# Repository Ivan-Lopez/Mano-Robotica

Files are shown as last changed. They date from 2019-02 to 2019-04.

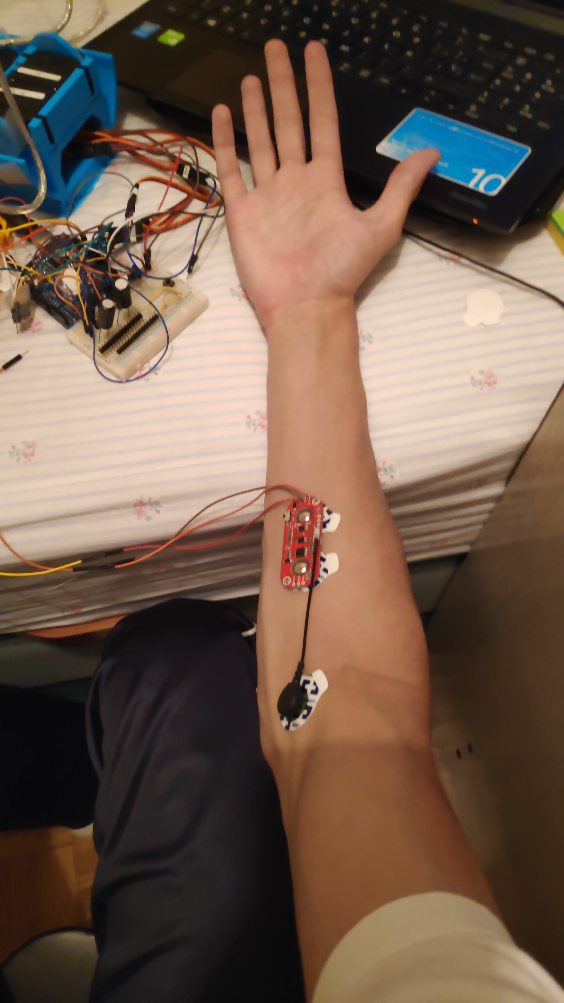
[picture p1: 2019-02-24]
Images/others/MuscleSensor-Colocación en el brazo.jpg

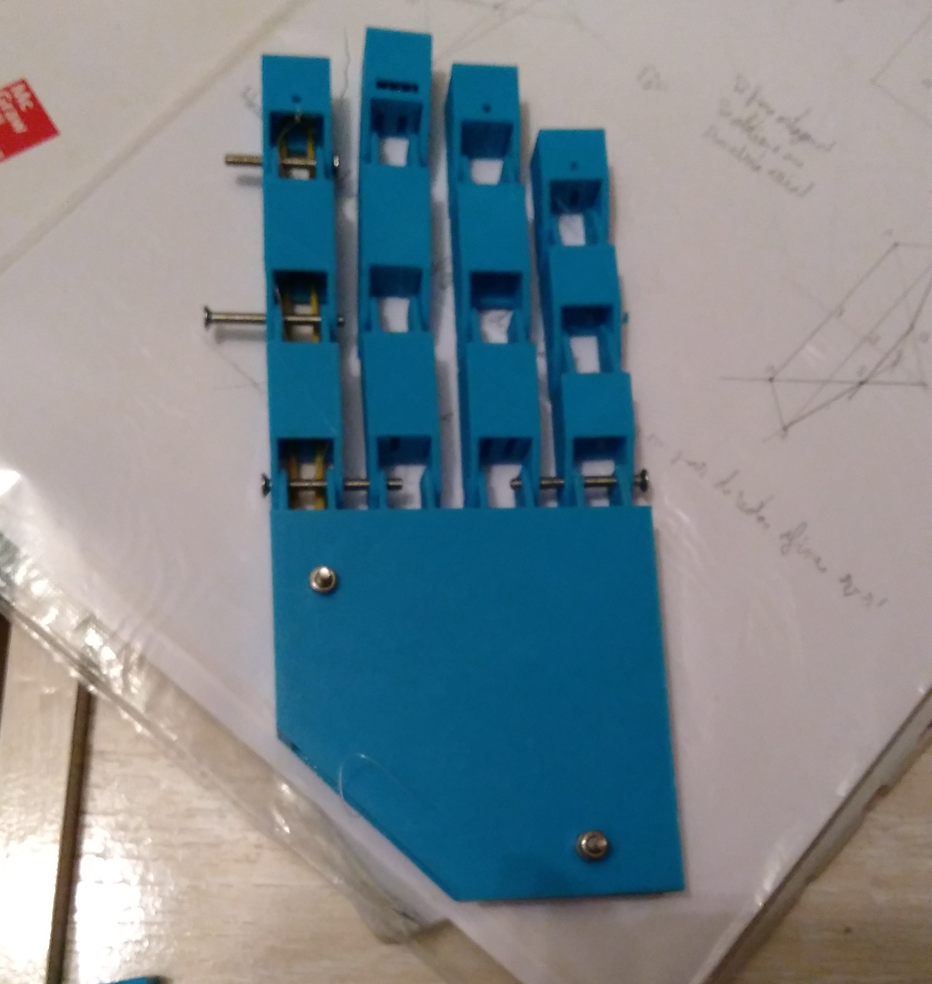
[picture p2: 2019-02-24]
Images/others/palma1(1).png

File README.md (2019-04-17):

# Mano Robotica [ES]

Este es el proyecto de investigación de Bachillerato que se presentó para el curso 2018-2019 en el IES Palas Atenea.
El diseño se comenzó en la versión 0.15 de FreeCAD y después se continuó en la 0.16.

Dentro de la carpeta FreeCAD-master file, se encuentra el diseño global, el archivo "mano+pulgar.FCStd", con todos los intentos fallidos y pruebas escondidos (y una mala organización debido a que fue mi primer proyecto tan grande).

En la carpeta Diseños se encuentran todas las piezas en formato .stl para su directa impresión.

En la carpeta Arduino files, los programas Arduino para controlar la mano mediante los sensores flexibles o musculares.

Algunos vídeos del funcionamiento:
  - Sensores flexibles(Guante): https://drive.google.com/file/d/11Kb9g7OQmceqUr2YcnktoNpW7YNgNKIl/view?usp=sharing 
  - Sensores musculares: https://drive.google.com/file/d/1Bvhk9YkBuKc7p54vJVHqvYE_SyeNIpOb/view?usp=sharing

# Robotic Hand [EN]

This is the project presented in the 2018-2019 schoolyear at Palas Atenea High School.
The design was started in the 0.15 version of FreeCAD and then continued in the 0.16 version.

In the "FreeCAD-master file" directory, you can find the global design ("mano+pulgar.FCStd"), which includes all the fail attempts and tests hidden (and a poor organization due to it was my first project of its size).

In the "Designs" directory, you can fin all the parts in .stl format.

In the "Arduino Files", the Arduino programs to control the hand through the flex sensor or muscle sensors.

Some videos:
  - Flex sensors (glove): https://drive.google.com/file/d/11Kb9g7OQmceqUr2YcnktoNpW7YNgNKIl/view?usp=sharing 
  - Muscle sensors: https://drive.google.com/file/d/1Bvhk9YkBuKc7p54vJVHqvYE_SyeNIpOb/view?usp=sharing

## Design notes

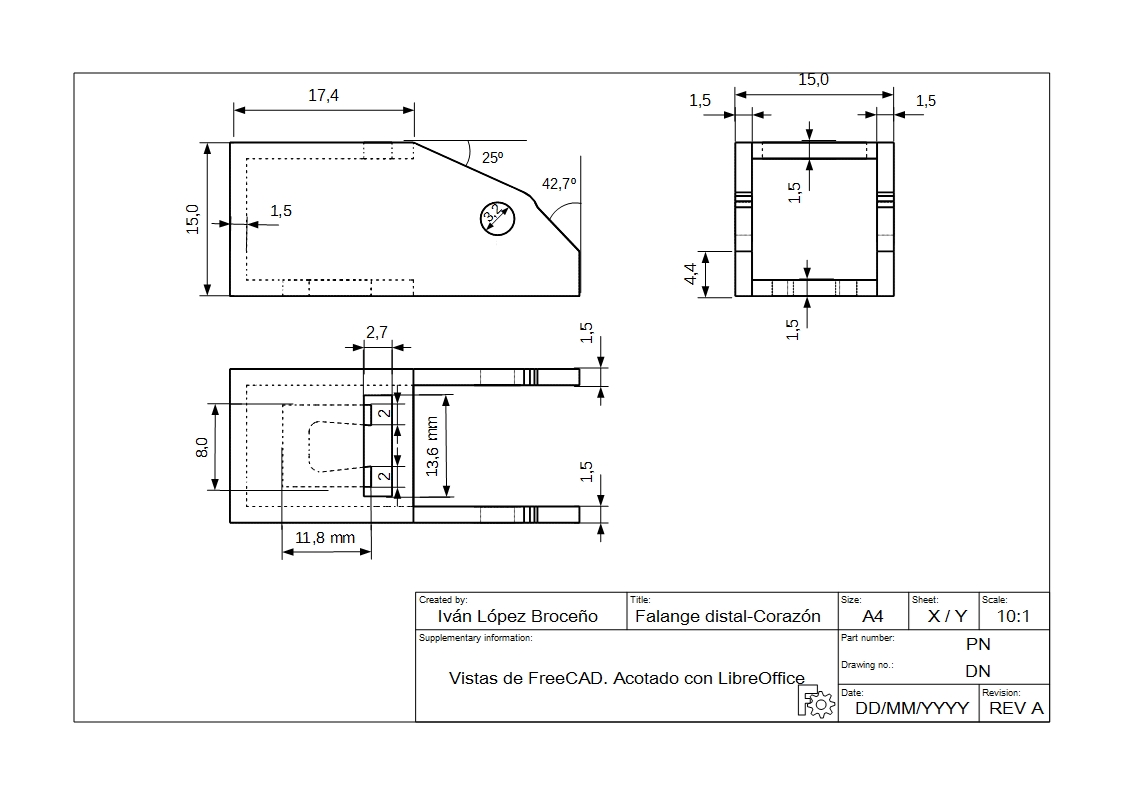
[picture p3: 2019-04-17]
Images/plans/falange distal-corazon.jpg

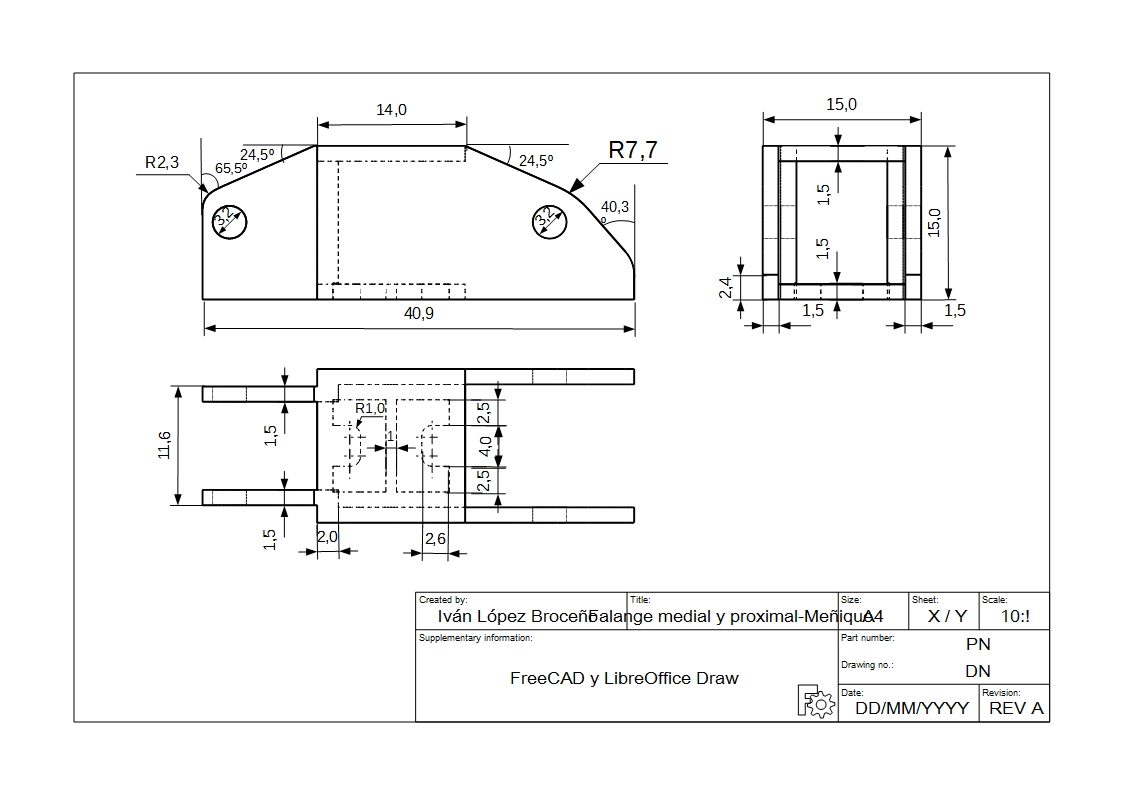
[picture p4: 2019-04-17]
Images/plans/falange medial y proximal-meñique.jpg

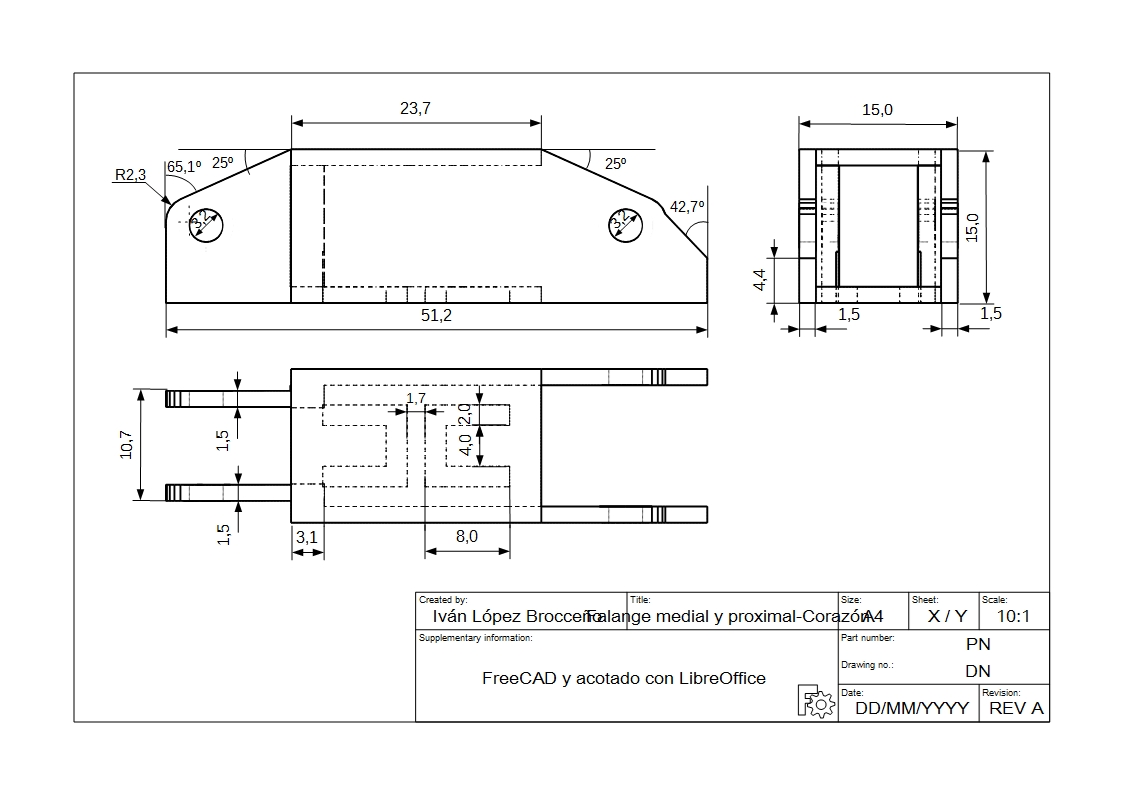
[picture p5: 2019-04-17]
Images/plans/Falange medial y proximal-Corazón.jpg

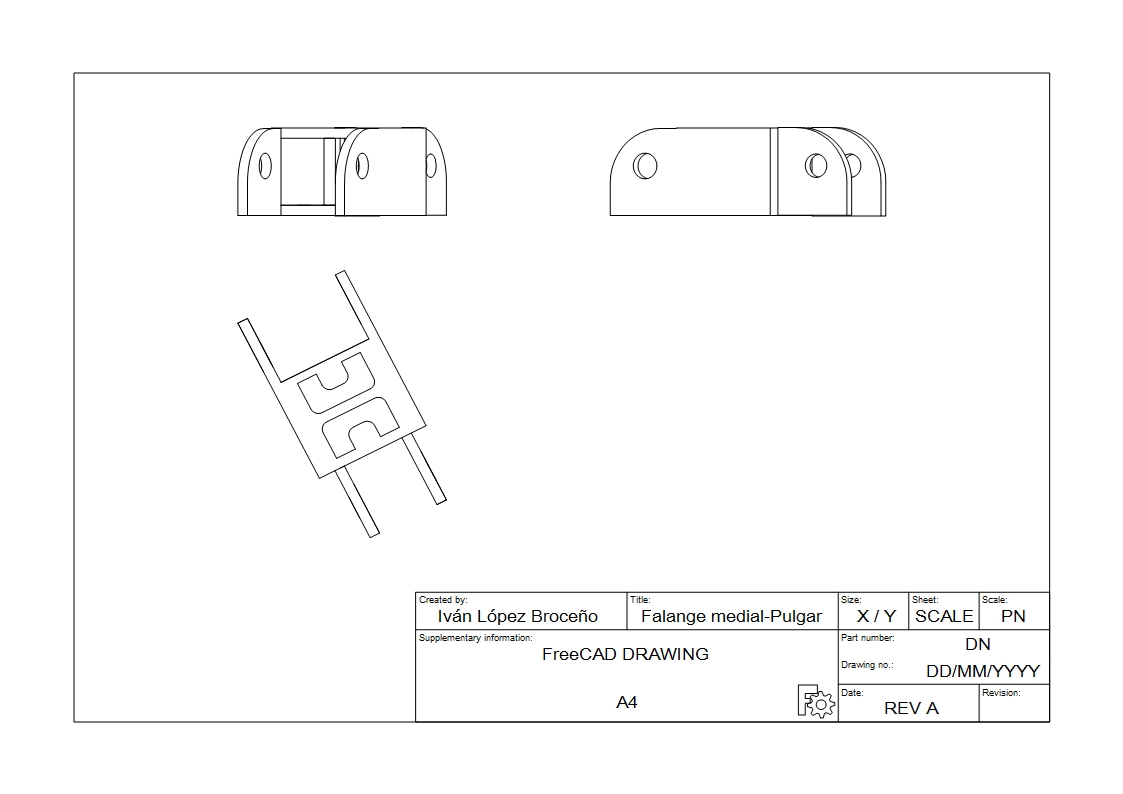
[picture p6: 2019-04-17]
Images/plans/falange medial-pulgar.jpg

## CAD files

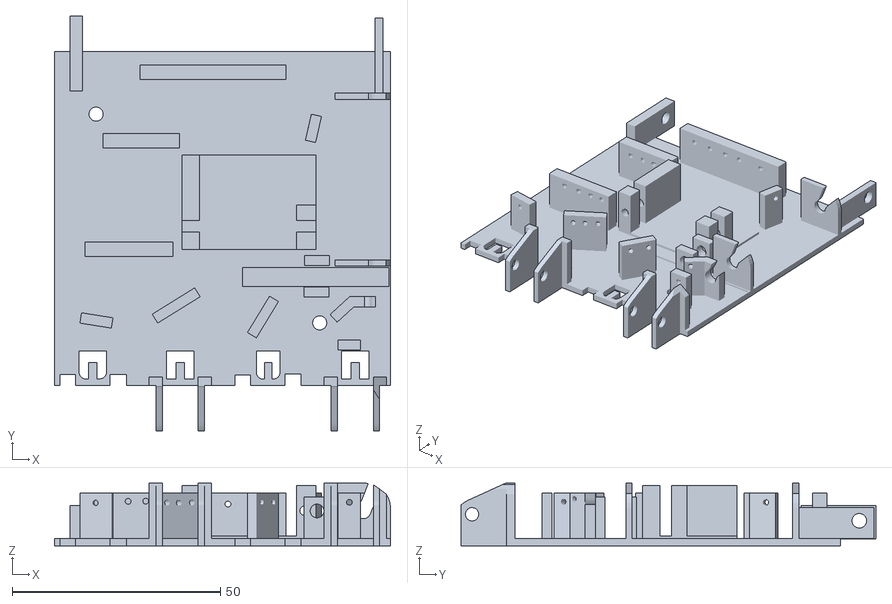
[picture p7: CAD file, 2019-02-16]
Diseños-Designs/Palma-Palm/PalmaInferior.stl
80.7 x 99.6 x 15.0

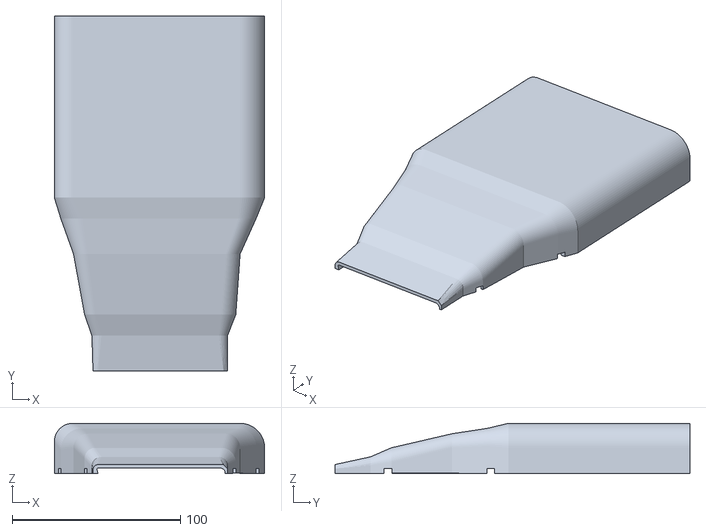
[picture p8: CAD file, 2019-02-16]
Diseños-Designs/Antebrazo-Forearm/TapaAntebrazo-ForearmCover.stl
125.0 x 211.0 x 29.9

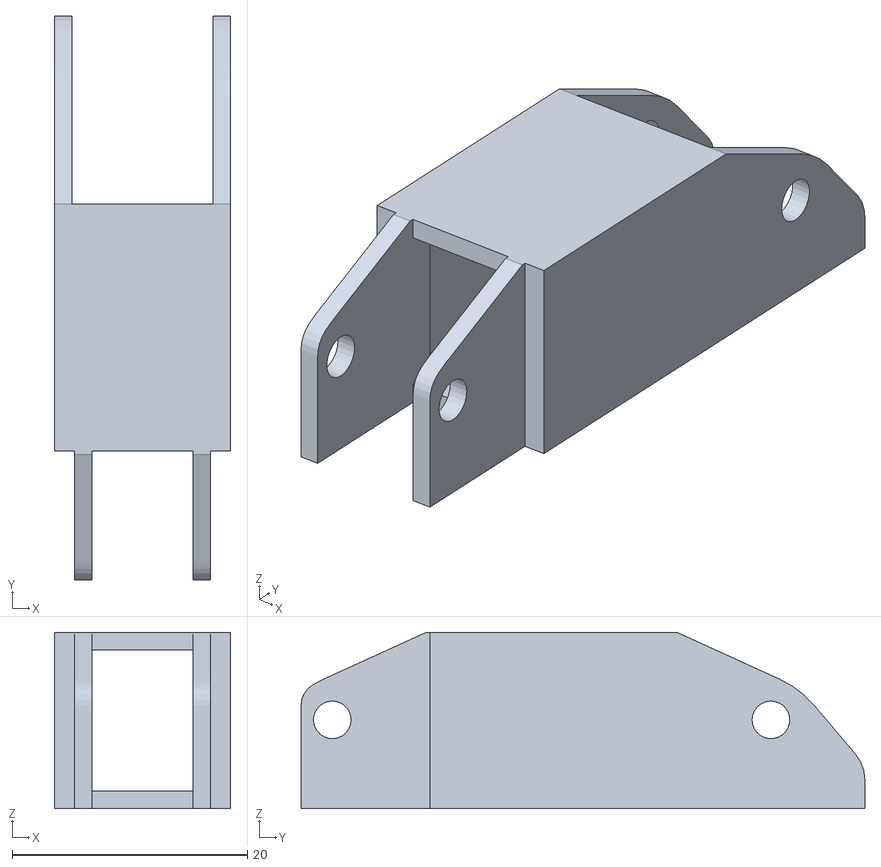
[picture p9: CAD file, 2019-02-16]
Diseños-Designs/Dedos-Fingers/Anular-Ring Finger/falange2-anular.stl
15.0 x 48.0 x 15.0

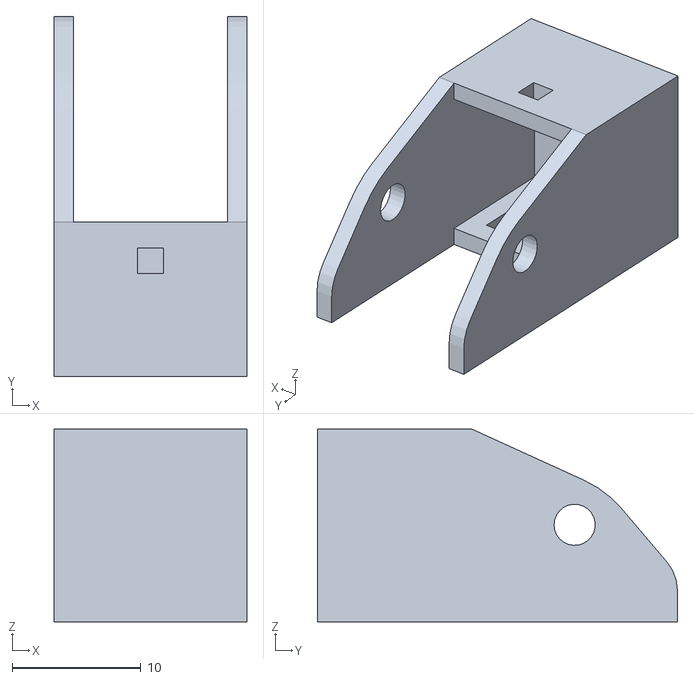
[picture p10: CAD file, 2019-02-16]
Diseños-Designs/Dedos-Fingers/Meñique-Little Finger/falange1-meñique.stl
15.0 x 28.0 x 15.0

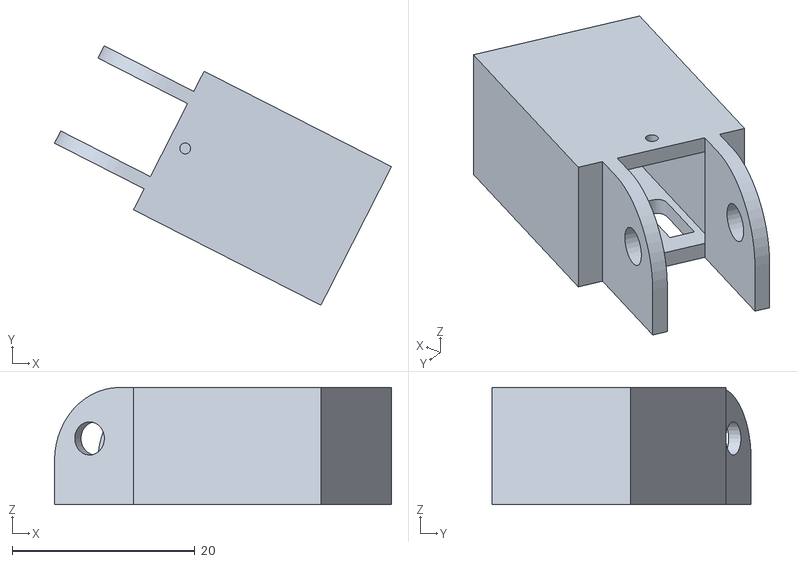
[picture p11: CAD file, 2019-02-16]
Diseños-Designs/Dedos-Fingers/Pulgar-Thumb/falange1-pulgar.stl
36.8 x 28.4 x 12.8

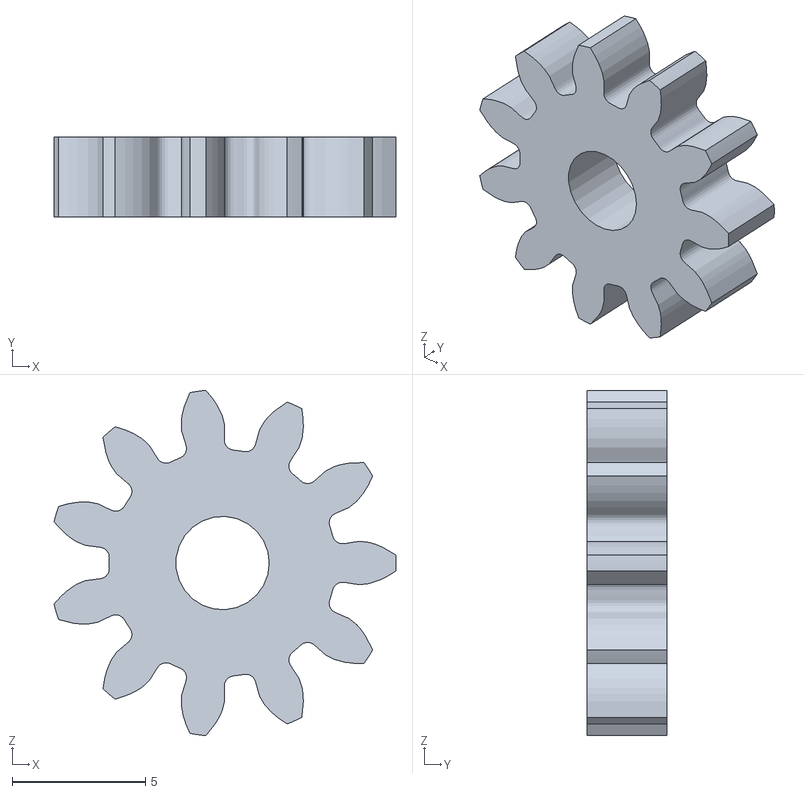
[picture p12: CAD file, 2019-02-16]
Diseños-Designs/Palma-Palm/Engranajes/engranaje-pulgar(piñon)).stl
12.8 x 3.00 x 12.9

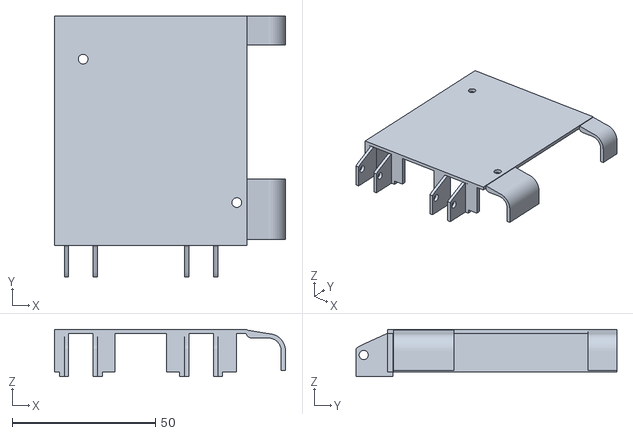
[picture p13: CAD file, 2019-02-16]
Diseños-Designs/Palma-Palm/PalmaSuperior.stl
80.7 x 91.1 x 16.5

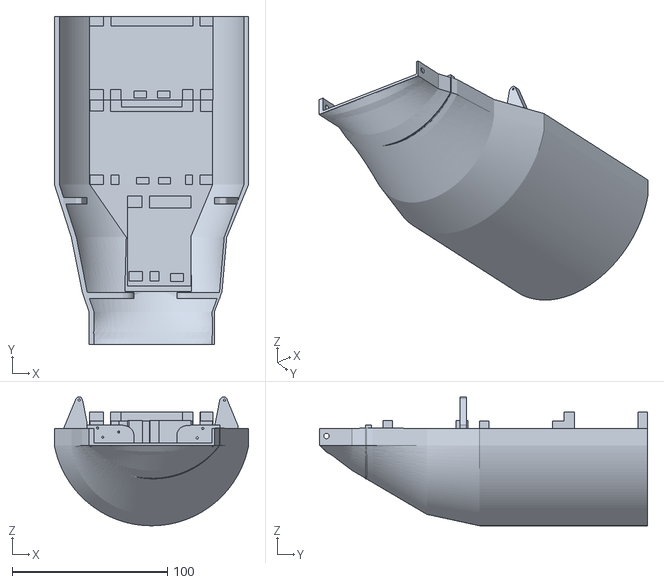
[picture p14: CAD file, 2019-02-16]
Diseños-Designs/Antebrazo-Forearm/Antebrazo(inferior)-Forearm.stl
125.0 x 211.0 x 82.7

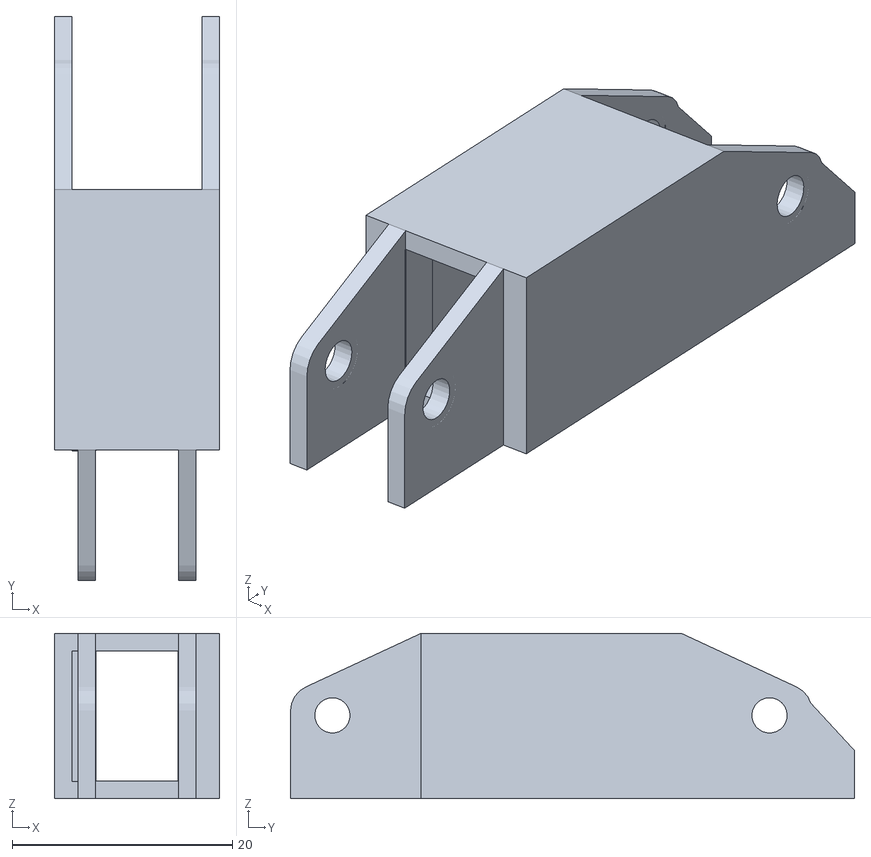
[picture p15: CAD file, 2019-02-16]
Diseños-Designs/Dedos-Fingers/Corazón-Middle Finger/falange2-corazon.stl
15.0 x 51.2 x 15.0

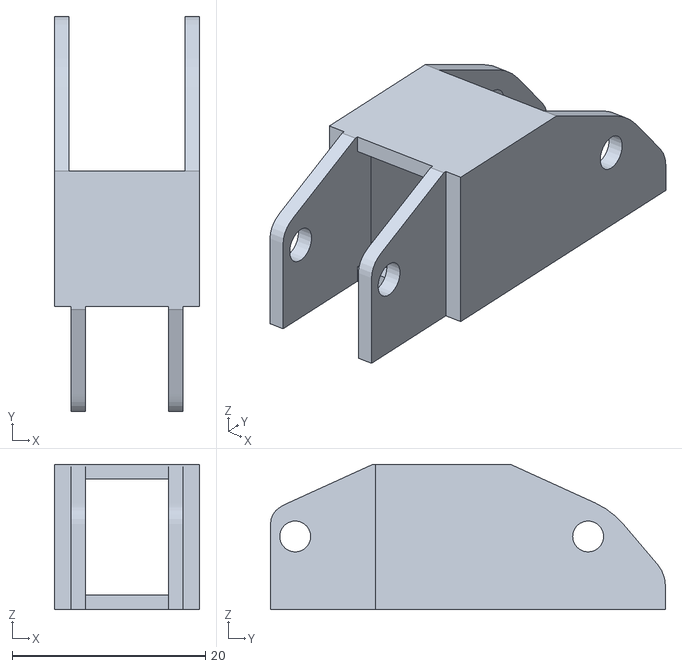
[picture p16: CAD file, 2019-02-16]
Diseños-Designs/Dedos-Fingers/Meñique-Little Finger/falange3-meñique.stl
15.0 x 40.9 x 15.0

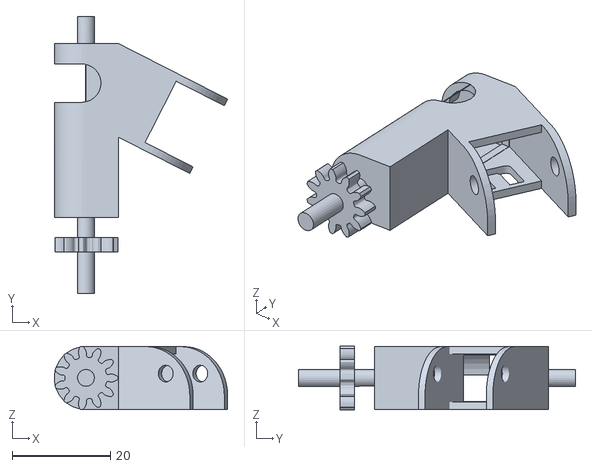
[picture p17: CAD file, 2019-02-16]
Diseños-Designs/Dedos-Fingers/Pulgar-Thumb/eje-falange3-pulgar.stl
35.3 x 56.4 x 12.9

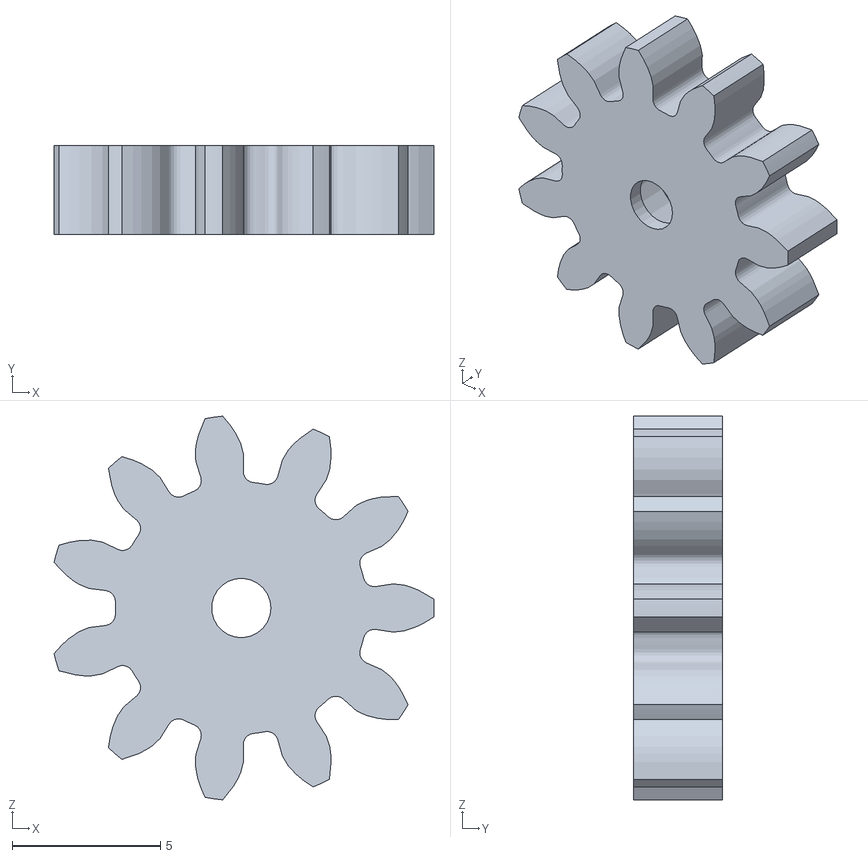
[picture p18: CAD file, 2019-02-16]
Diseños-Designs/Palma-Palm/Engranajes/engranaje-pulgar(motor).stl
12.8 x 3.00 x 12.9

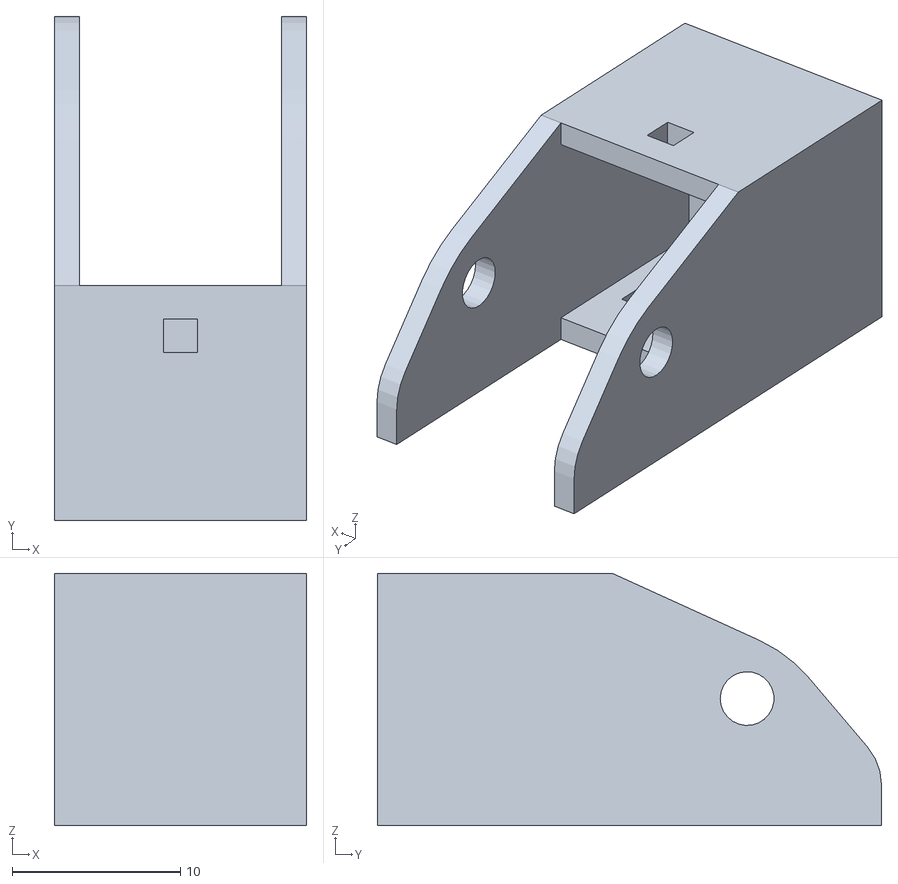
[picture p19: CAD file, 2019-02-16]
Diseños-Designs/Dedos-Fingers/Anular-Ring Finger/falange1-anular.stl
15.0 x 30.0 x 15.0

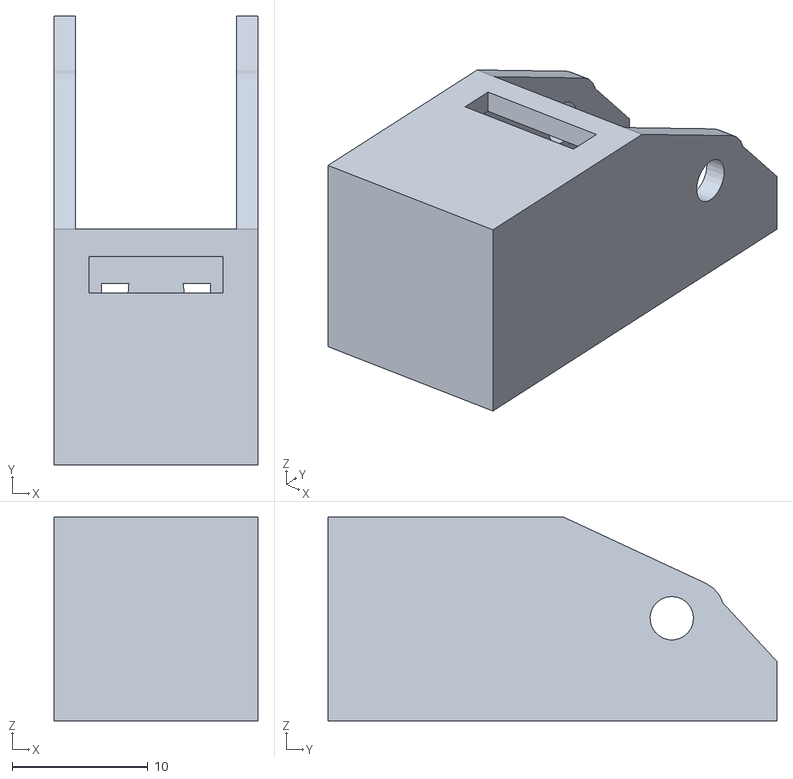
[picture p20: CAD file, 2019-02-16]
Diseños-Designs/Dedos-Fingers/Corazón-Middle Finger/falange1-corazon.stl
15.0 x 33.1 x 15.0

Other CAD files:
Diseños-Designs/Dedos-Fingers/Índice-Index Finger/falange2-indice.stl
Diseños-Designs/Dedos-Fingers/Anular-Ring Finger/falange3-anular.stl
Diseños-Designs/Dedos-Fingers/Índice-Index Finger/falange3-indice.stl
Diseños-Designs/Dedos-Fingers/Meñique-Little Finger/falange2-meñique.stl
Diseños-Designs/Dedos-Fingers/Corazón-Middle Finger/falange3-corazonV2.stl
Diseños-Designs/Dedos-Fingers/Pulgar-Thumb/falange2-pulgar.stl
Diseños-Designs/Dedos-Fingers/Índice-Index Finger/falange1-indice.stl
Diseños-Designs/Dedos-Fingers/Índice-Index Finger/falange3-indiceV2.stl

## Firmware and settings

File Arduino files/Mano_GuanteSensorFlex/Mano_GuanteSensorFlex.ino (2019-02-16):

/*En este programa se recoge la información de flexión de los sensores del
guante a través de su cambio de resistencia. 

Una vez obtenido el valor de entrada que va de 0-1023, reducimos el rango
de 300 a 600 aprox donde 300 es el valor cuando el sensor está recto y
600 cuando el sensor está flexionado.

Para evitar cambios continuos, recogemos 1 dato por dedo cada 5 ms. Al 
llegar a 30 datos recogidos, hacemos la media.

Después gracias a map() convertimos el valor medio de este rango de
mínimo y máximo del sensor(300-600) al rango de posición de cada motor
(0-135, por ejemplo).

Finalmente, enviamos las pociciones resultantes a los motores 
con servo.write() e imprimimos estos datos por el puerto serie para 
poder visualizarlos en el ordenador. Si se alimenta el guante y la mano 
mediante una batería y no por USB, esa parte se puede comentar 
*/

//variables para asignar a cada entrada analógica un nombre
const int FLEX_PIN1 = A0; // Pin connected to voltage divider output
const int FLEX_PIN2 = A1;
const int FLEX_PIN3 = A2;
const int FLEX_PIN4 = A3;
const int FLEX_PIN5 = A4;
const int FLEX_PIN6 = A5;//este es el servo pequeñode la palma

#include <Servo.h>;
//incluimos la librería servo para después 
//crear los 6 servos y poder moverlos
Servo servo2;
Servo servo1;
Servo servo3;
Servo servo4;
Servo servo5;
Servo servo6;

const int intervalo = 500;
unsigned long previousMillis=0;

//Variables para realizar la media
int Lecturas1[30];
int Lecturas2[30];
int Lecturas3[30];
int Lecturas4[30];
int Lecturas5[30];
int Lecturas6[30];
int Total1=0;
int Total2=0;
int Total3=0;
int Total4=0;
int Total5=0;
int Total6=0;
int i=0;
int media1=0;
int media2=0;
int media3=0;
int media4=0;
int media5=0;
int media6=0;

//posiciones resultantes que serán enviadas a cada motor
int pos1=0;
int pos2=0;
int pos3=155;
int pos4=155;
int pos5=0;
int pos6=80;
void setup() 
{ //enlazamos cada servo a una salida para poder controlarnos
  servo1.attach(5);
  servo2.attach(6);
  servo3.attach(9);
  servo4.attach(3);
  servo5.attach(10);
  servo6.attach(11);

  //enviamos una orden de posición a los servos 
  //para que los dedos vuelvan a estar derechos
  servo1.write(0);
  servo2.write(0);
  servo3.write(155);
  servo4.write(155);
  servo5.write(0);
  servo6.write(80);
  
  Serial.begin(9600); //inicializamos el puerto serie  
                      //para ver los datos resultantes
  
  pinMode(FLEX_PIN1, INPUT); //Establecemos 
  pinMode(FLEX_PIN2, INPUT); //las entradas para
  pinMode(FLEX_PIN3, INPUT); //los sensores
  pinMode(FLEX_PIN4, INPUT);
  pinMode(FLEX_PIN5, INPUT);
  pinMode(FLEX_PIN6, INPUT);

 //Reseteamos a 0 todas las posiciones de los arrays
  for(i=0;i<30;i++){
    Lecturas1[i]=0;
    }
    i=0;
  for(i=0;i<30;i++){
    Lecturas2[i]=0;
    }
    i=0;
  for(i=0;i<30;i++){
    Lecturas3[i]=0;
    }
    i=0;
  for(i=0;i<30;i++){
    Lecturas4[i]=0;
    }
    i=0;
  for(i=50;i<30;i++){
    Lecturas5[i]=0;
    }
    i=0;
  for(i=0;i<30;i++){
    Lecturas6[i]=0;
    } 
    i=0; 
    
    previousMillis=millis(); // 5/8/18 a las 21:01
}

void loop() 
{ //Realizamos una lectura cada5ms, por lo que el servo se mueve cada 150ms
  if(millis()-previousMillis>=5){   
  //Restamos los valores guardados anteriormente
  Total1=Total1-Lecturas1[i];
  Total2=Total2-Lecturas2[i];
  Total3=Total3-Lecturas3[i];
  Total4=Total4-Lecturas4[i];
  Total5=Total5-Lecturas5[i];
  Total6=Total6-Lecturas6[i];
  //Agregamos la nueva lectura
  Lecturas1[i] = analogRead(FLEX_PIN1);
  Lecturas2[i] = analogRead(FLEX_PIN2);
  Lecturas3[i] = analogRead(FLEX_PIN3);
  Lecturas4[i] = analogRead(FLEX_PIN4);
  Lecturas5[i] = analogRead(FLEX_PIN5);
  Lecturas6[i] = analogRead(FLEX_PIN6);
  //Sumamos la nueva lectura al total
  Total1=Total1+Lecturas1[i];
  Total2=Total2+Lecturas2[i];
  Total3=Total3+Lecturas3[i];
  Total4=Total4+Lecturas4[i];
  Total5=Total5+Lecturas5[i];
  Total6=Total6+Lecturas6[i];
  i++;
  //Calcula la media si el array está completo, y la envía al servo 
  if(i>=30){
    i=0;
    media1=Total1/30;
    media2=Total2/30;
    media3=Total3/30;
    media4=Total4/30;
    media5=Total5/30;
    media6=Total6/30;
    pos1=map(media1,532,311,0,135);
               //estos valores vienen dados del analogRead()
               //que hemos establecido tras probar previamente
               //los sensores para crear un máximo y un mínimo de flexión
    pos2=map(media2,542,358,0,135);
    pos3=map(media3,618,389,155,20);
    pos4=map(media4,624,400,155,20);
    pos5=map(media5,620,460,100,160);
    pos6=map(media6,660,580,80,175);
   
    //añadimos condicionales de control para no dañar los servos
    if(pos1>140){
      pos1=140;
      }else if(pos1<0){
        pos1=0;
        }
     if(pos2>140){
      pos2=140;
      }else if(pos2<0){
        pos2=0;
        }
     if(pos3>160){
      pos3=160;
      }else if(pos3<15){
        pos3=15;
        }
      if(pos4>160){
      pos4=160;
      }else if(pos4<10){
        pos4=10;
        }    
      if(pos5>160){
        pos5=160;
        }else if(pos5<100){
          pos5=100;
          }
      if(pos6>175){
        pos6=175;
        }else if(pos6<80){
          pos6=80;
          }
          
    servo1.write(pos1);             
    servo2.write(pos2);
    servo3.write(pos3);
    servo4.write(pos4);
    servo5.write(pos5);
    servo6.write(pos6);
    //Envía los datos al Serial Plotter
    Serial.print(pos1);
    Serial.print(' ');
    Serial.print(pos2);
    Serial.print(' ');
    Serial.print(pos3);
    Serial.print(' ');
    Serial.print(pos4);
    Serial.print(' ');
    Serial.print(pos5);
    Serial.print(' ');
    Serial.println(pos6);  
    }
   previousMillis=millis();
  }
  
}

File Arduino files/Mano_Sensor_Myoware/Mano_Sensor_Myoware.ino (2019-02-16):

/*
En este programa se mide el valor del sensor muscular que va de 0 a 1023
y este dato se convierte al rango de cada motor. De esta manera conseguimos
las 6 posiciones a partir de un solo valor. 
Cuando se flexione la muñeca, el valor medido aumentará y, por tanto,
la mano impresa en 3D se cerrará.

*/
const int muscle_sensor = A5; // Pin connected to voltage divider output

#include <Servo.h>;
Servo servo2;
Servo servo1;
Servo servo3;
Servo servo4;
Servo servo5;
Servo servo6;

unsigned long previousMillis=0;
int pos1=0;
int pos2=0;
int pos3=155;
int pos4=155;
int pos5=0;
int pos6=80;
int sensor=0; //Valor del sensor
void setup() 
{
  servo1.attach(5);
  servo2.attach(6);
  servo3.attach(9);
  servo4.attach(3);
  servo5.attach(10);
  servo6.attach(11);
  
  servo1.write(0);
  servo2.write(0);
  servo3.write(155); //al estar colocados de un lado opuesto 
  servo4.write(155); //a los otros dos su giro está invertido
  servo5.write(0);
  servo6.write(80);
  
  Serial.begin(9600);
  
  pinMode(muscle_sensor, INPUT);
    
    previousMillis=millis(); // 5/8/18 a las 21:01
}

void loop() 
{  if( millis()-previousMillis >= 30){
    sensor = analogRead(muscle_sensor);

pos1=map(sensor,14,1023,0,135); 
    pos2=map(sensor,14,1023,0,135);
    pos3=map(sensor,14,1023,155,20);
    pos4=map(sensor,14,1023,155,20); //el índice tiene problemas paar moverse 
                                    //totalmente por lo que aumento el rango
    pos5=map(sensor,14,1023,100,140);
    pos6=map(sensor,14,1023,80,175);
   
    //añadimos condicionales de contraol para no dañar los servos
    if(pos1>140){
      pos1=140;
      }else if(pos1<0){
        pos1=0;
        }
     if(pos2>140){
      pos2=140;
      }else if(pos2<0){
        pos2=0;
        }
     if(pos3>160){
      pos3=160;
      }else if(pos3<15){
        pos3=15;
        }
      if(pos4>160){
      pos4=160;
      }else if(pos4<10){
        pos4=10;
        }    
      if(pos5>140){
        pos5=140;
        }else if(pos5<100){
          pos5=100;
          }
      if(pos6>175){
        pos6=175;
        }else if(pos6<80){
          pos6=80;
          }
          
    servo1.write(pos1);             
    servo2.write(pos2);
    servo3.write(pos3);
    servo4.write(pos4);
    servo5.write(pos5);
    servo6.write(pos6);
    //Envía los datos al Serial Plotter[Desactivado]
    Serial.println(sensor);
 /*   Serial.print(pos1);
    Serial.print(' ');
    Serial.print(pos2);
    Serial.print(' ');
    Serial.print(pos3);
    Serial.print(' ');
    Serial.print(pos4);
    Serial.print(' ');
    Serial.print(pos5);
    Serial.print(' ');
    Serial.println(pos6);  
    }*/
   previousMillis=millis();
  }

}

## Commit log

2019-02-16 Arduino files update
2019-02-24 [ImgBot] Optimize images
    *Total -- 16,123.32kb -> 13,112.34kb (18.67%)
    /Images/others/palma1(1).png -- 3,540.49kb -> 2,585.68kb (26.97%)
    /Images/others/mano+brazo.png -- 6,568.87kb -> 5,242.08kb (20.2%)
    /Images/schemes/Esquema total, sensores flex.png -- 167.43kb -> 134.58kb (19.62%)
    /Images/others/dedoV2.jpg -- 1,662.69kb -> 1,409.58kb (15.22%)
    /Images/others/MuscleSensor-Colocación en el brazo.jpg -- 2,009.14kb -> 1,793.02kb (10.76%)
    /Images/others/IMG_20180927_234917.jpg -- 2,056.75kb -> 1,840.35kb (10.52%)
    /Images/schemes/esquema muscle sensor.png -- 117.94kb -> 107.05kb (9.23%)
2019-02-25 Changed name files
    [Antebrazo(inferior)-Forearm.stl, PalmaInferior.stl, PalmaSuperior.stl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]
